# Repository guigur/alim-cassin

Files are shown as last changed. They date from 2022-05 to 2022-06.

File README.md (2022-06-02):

# alim-cassin
## Présentation
Ce PCB est un shield pour Arduino UNO.

Son but principal est de fournir à partir d'une batterie externe un rail **7V** très propre au régulateur linéaire de l'Arduino tout en générant également une alimentation **5V** pour alimenter un servomoteur. L'alimentation externe peut être coupée du système grâce au connecteur JST-XH3 où un bouton d'arrêt d'urgent NC se doit être connecté.

En découplant les alimentations, cela évite les resets intempestifs de l'Arduino lors d'efforts du servomoteur.

La version 2 du montage dispose d'un connecteur JST-XH4 compatible Groove afin d'y connecter un périphérique externe (dans notre cas un module bluetooth).
Un pont diviseur de tension est connecté sur le pin A0 permet également de mesurer la tension d'entrée jusqu'à 14V.

Enfin des LEDs permettent de visualiser l'état des rails d'alimentation.

## Schéma électrique
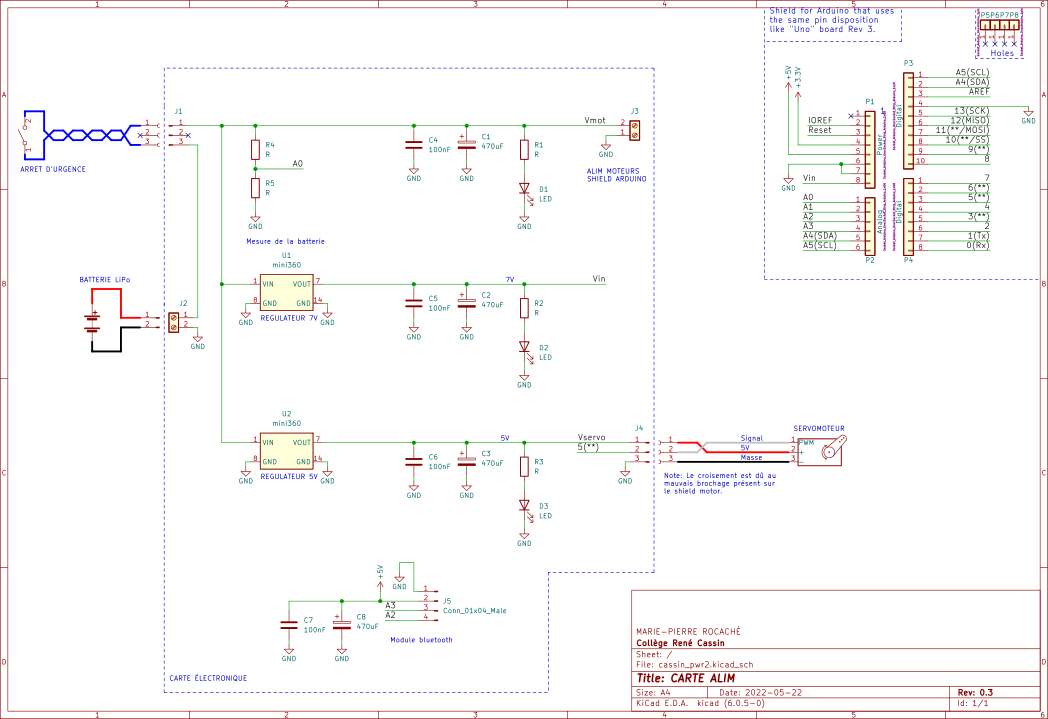
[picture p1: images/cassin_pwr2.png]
schematic Schéma électrique du PCB


## Rendu 3D
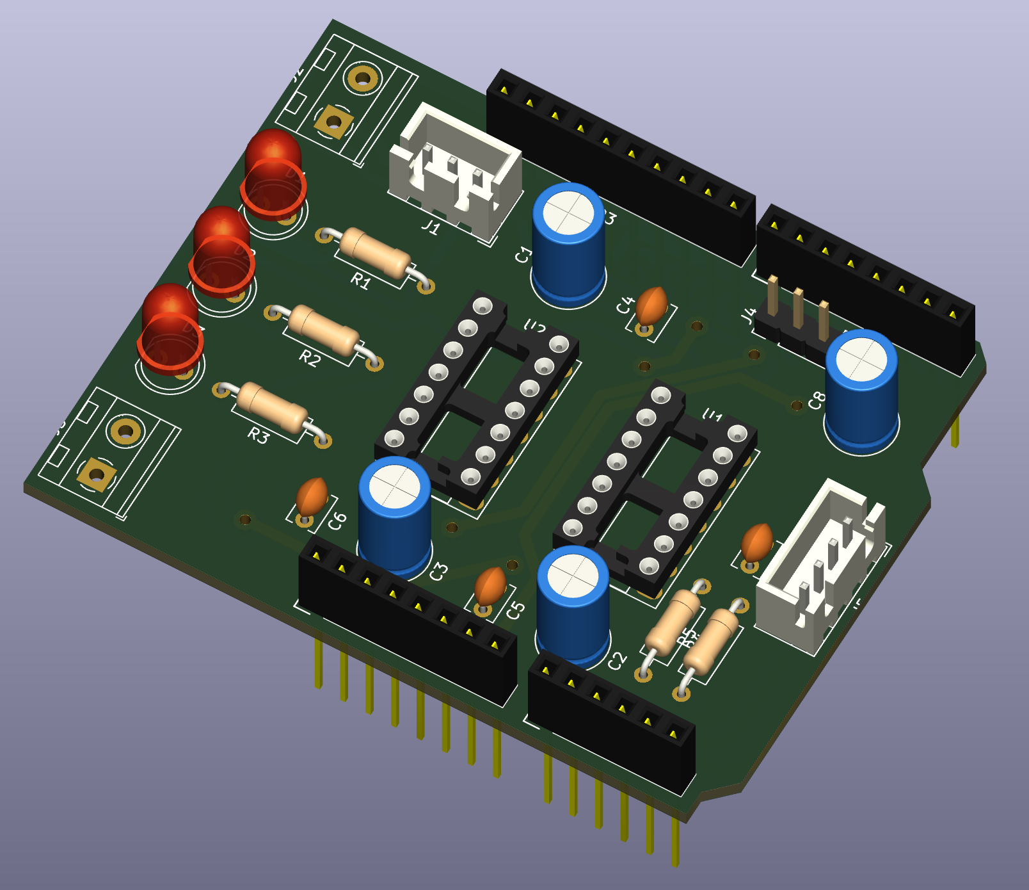
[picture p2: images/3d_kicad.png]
3D render of PCB Rendu 3D du PCB


## Le PCB (Prototype)
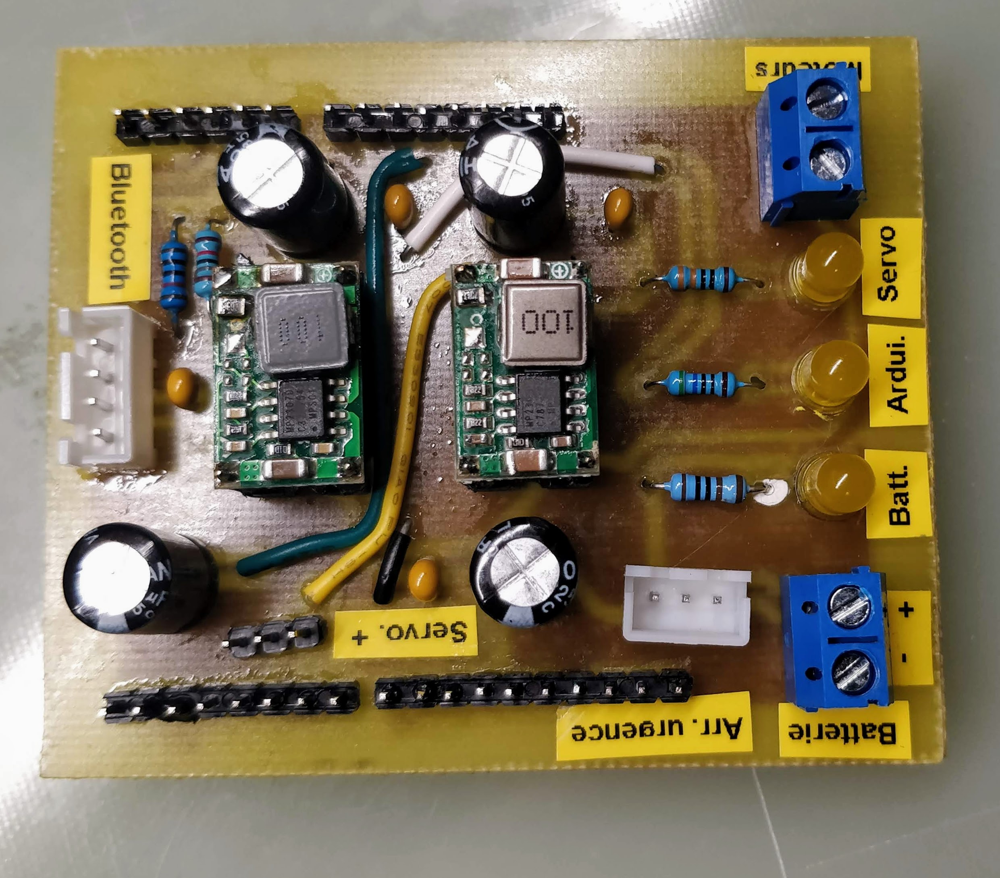
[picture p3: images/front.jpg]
Front of PCB Face du dessus du PCB

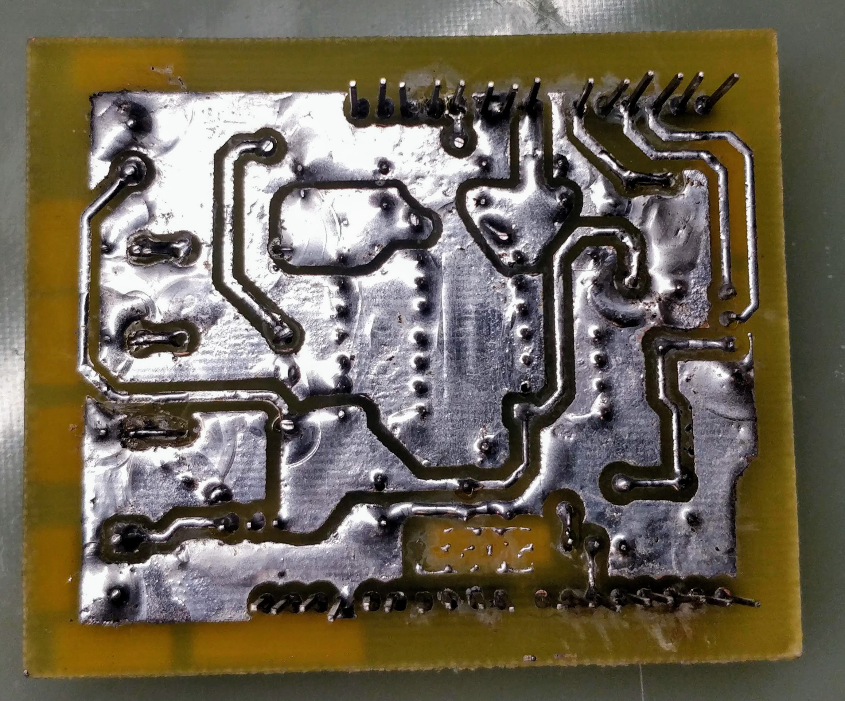
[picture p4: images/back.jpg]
Back of PCB Face du dessous du PCB


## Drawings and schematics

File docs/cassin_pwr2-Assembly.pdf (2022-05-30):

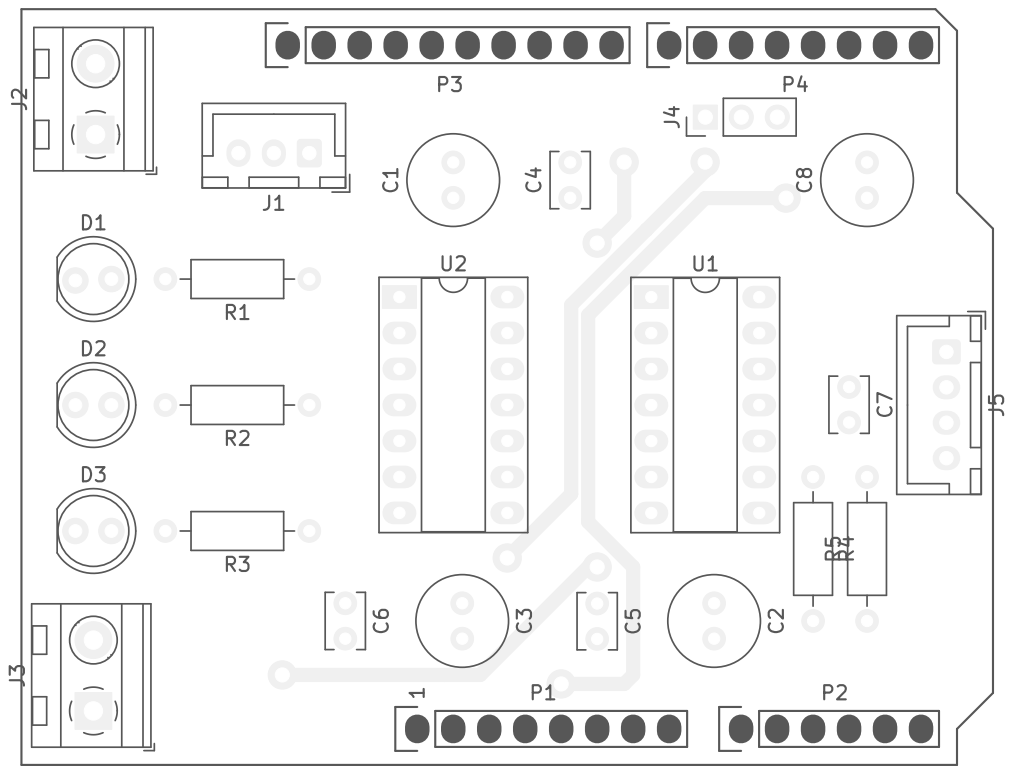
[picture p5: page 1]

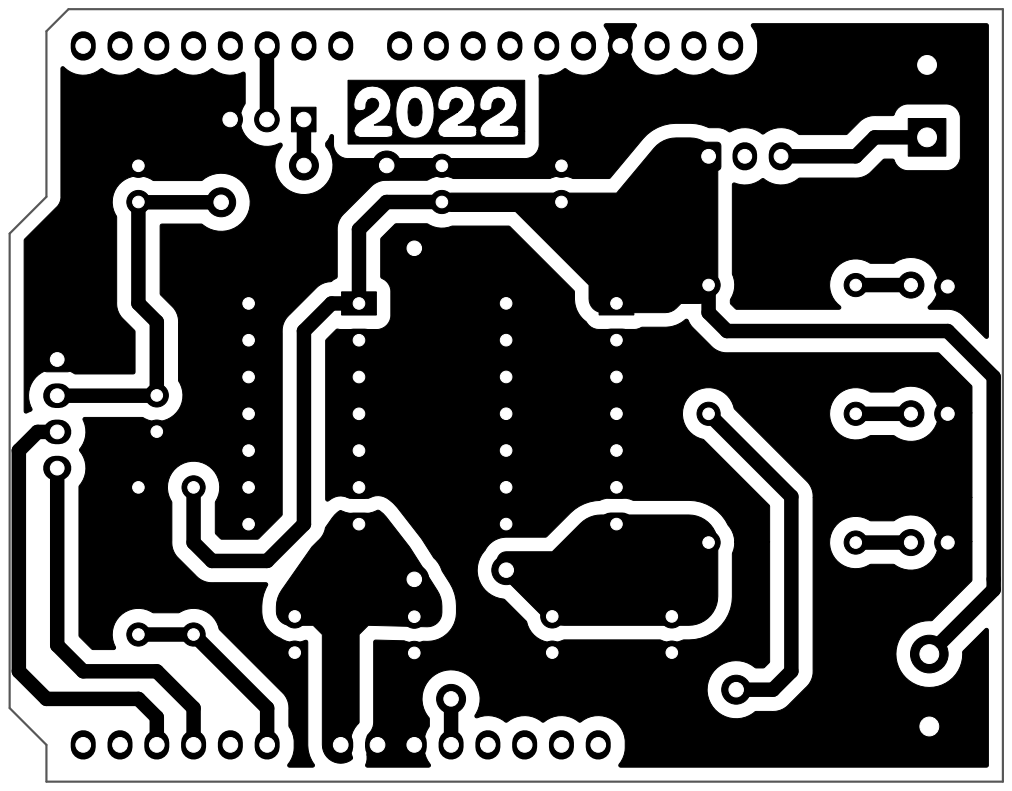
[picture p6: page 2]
D Date: lun. 30 mars 2015 KiCad E.D.A. kicad (6.0.5-0) Size: A4; Rev:; Id: 1/1 Title:; File: cassin_pwr2.kicad_pcb; Sheet: Assembly

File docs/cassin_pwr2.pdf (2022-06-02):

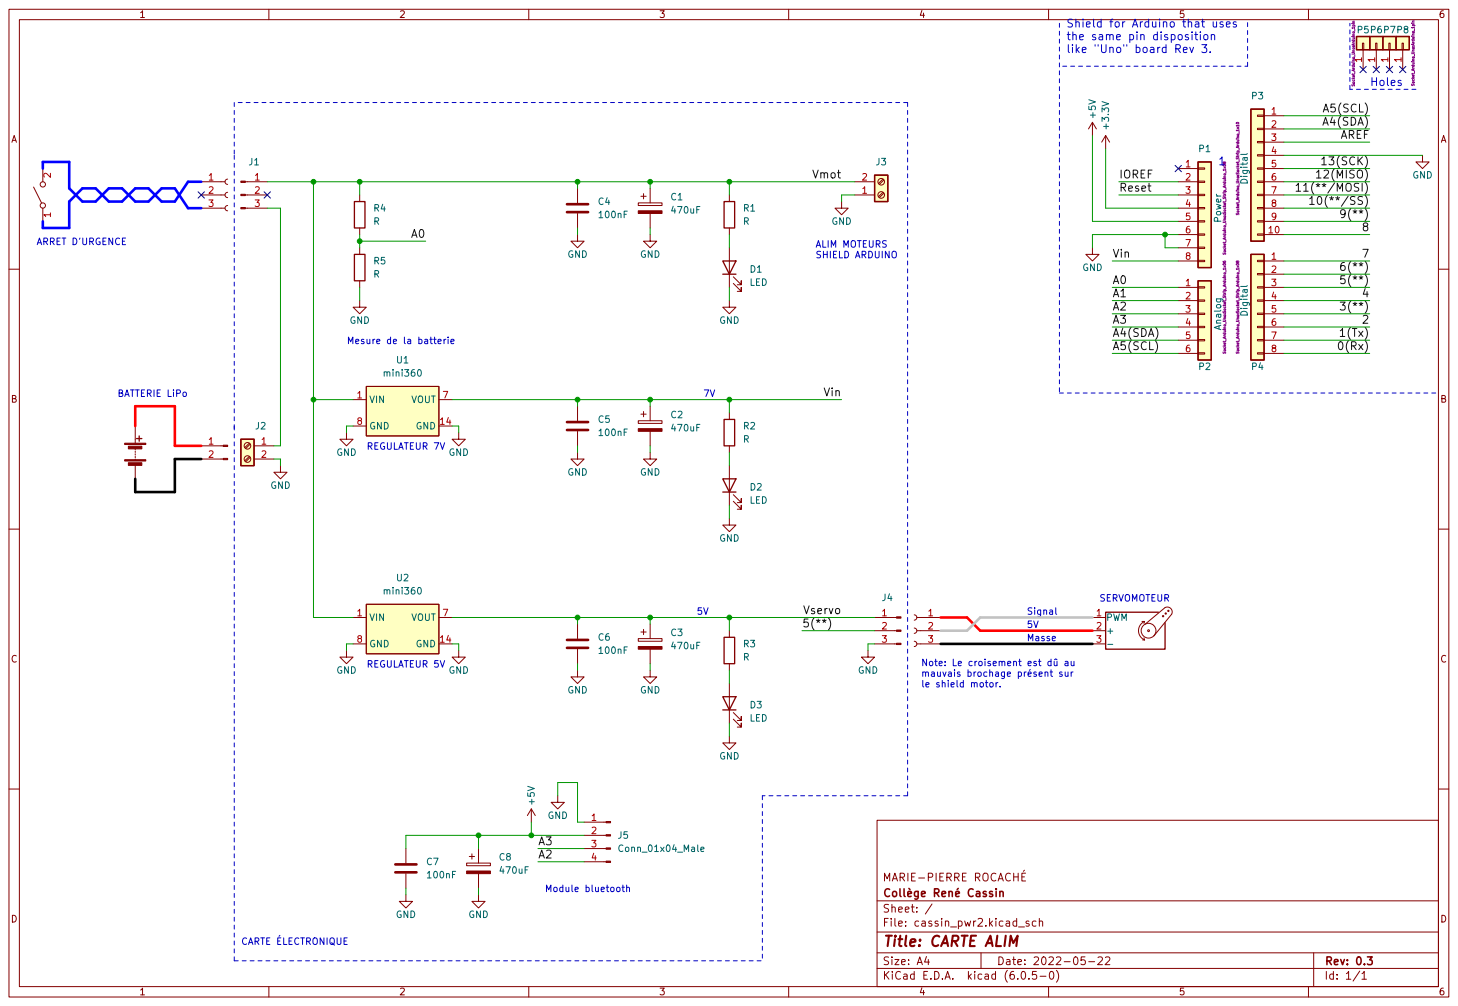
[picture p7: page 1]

1 Shield for Arduino that uses
the same pin disposition
like "Uno" board Rev 3.
J3 GND

Id: 1/1 Title: CARTE ALIM

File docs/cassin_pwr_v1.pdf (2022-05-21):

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

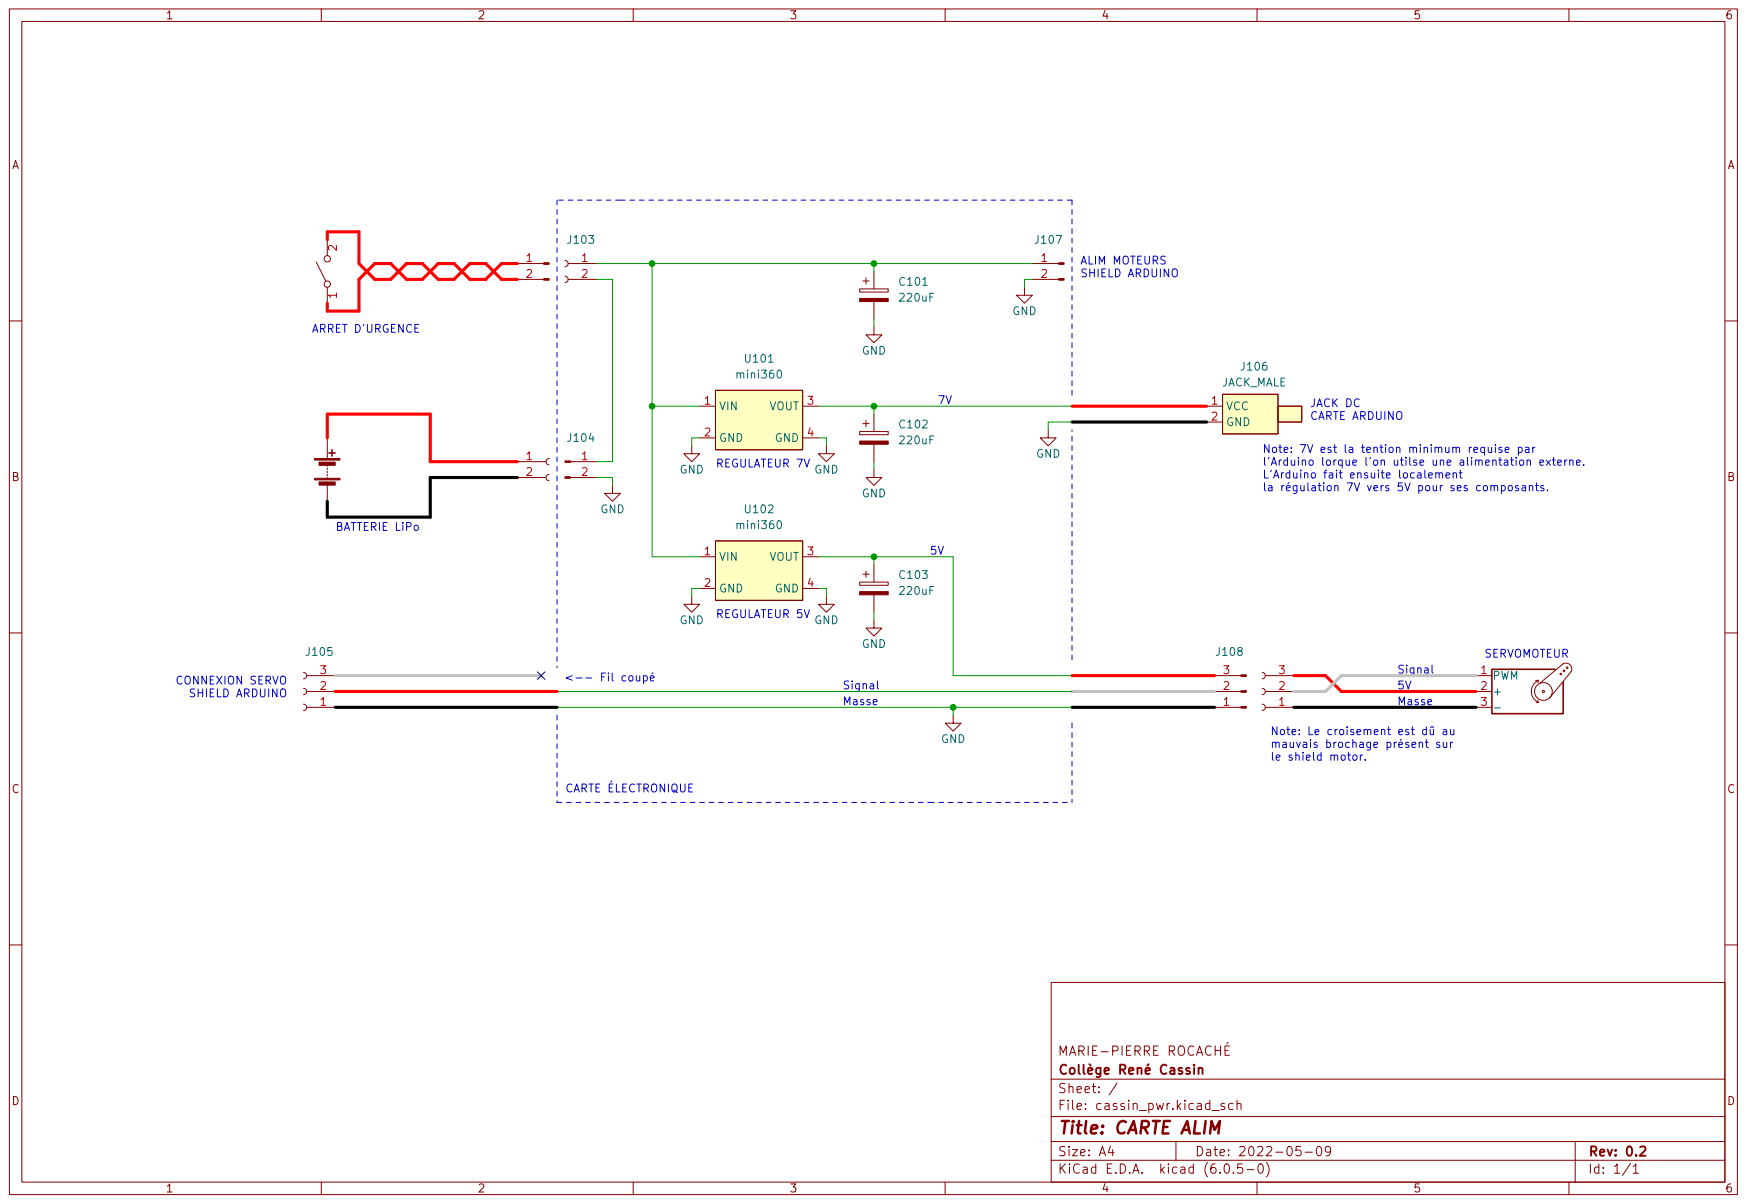
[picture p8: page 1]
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

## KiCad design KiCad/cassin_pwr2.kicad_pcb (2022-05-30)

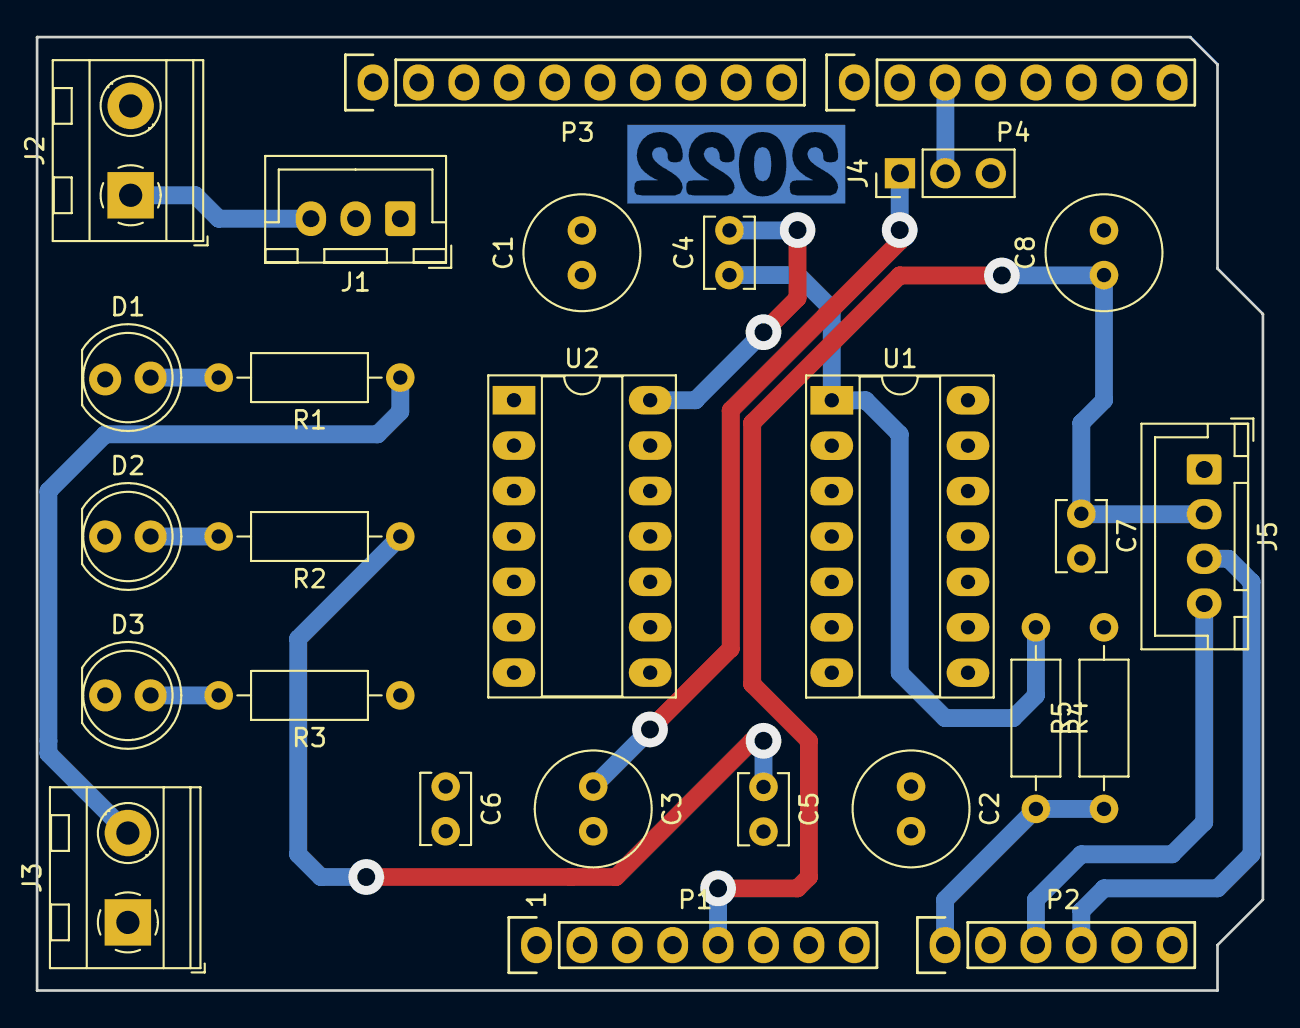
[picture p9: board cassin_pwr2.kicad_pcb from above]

Board: 2 copper layers, 68.6 x 53.3 mm, 28 parts (1 on the bottom side), 15 nets.

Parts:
C1, C2, C3, C8: 470uF; C_Radial_D6.3mm_H11.0mm_P2.50mm
C4, C5, C6, C7: 100nF; C_Disc_D3.8mm_W2.6mm_P2.50mm
D1, D2, D3: LED; LED_D5.0mm
J1: Conn_01x03_Male; JST_XH_B3B-XH-A_1x03_P2.50mm_Vertical
J2, J3: Screw_Terminal_01x02; TerminalBlock_MetzConnect_Type094_RT03502HBLU_1x02_P5.00mm_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
J4: Conn_01x03_Male; PinHeader_1x03_P2.54mm_Vertical
J5: Conn_01x04_Male; JST_XH_B4B-XH-A_1x04_P2.50mm_Vertical
P1: Power; Socket_Strip_Arduino_1x08
P2: Analog; Socket_Strip_Arduino_1x06
P3: Digital; Socket_Strip_Arduino_1x10
P4: Digital; Socket_Strip_Arduino_1x08
R1, R2, R3, R4, R5: R; R_Axial_DIN0207_L6.3mm_D2.5mm_P10.16mm_Horizontal
U1, U2: mini360; DIP-14_W7.62mm_Socket_LongPads
kibuzzard-628A722A: G***; kibuzzard-628A722A

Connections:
+5V: C7.1, C8.1, J5.2, P1.5
/5(**): J4.2, P4.3
/A0: P2.1, R4.2, R5.1
/A2: J5.4, P2.3
/A3: J5.3, P2.4
/A4(SDA): P2.5, P3.2
/A5(SCL): P2.6, P3.1
/Vin: C2.1, C5.1, P1.8, R2.1, U1.7 (VOUT)
/Vmot: C1.1, C4.1, J1.1, J3.2, R1.1, R4.1, U1.1 (VIN), U2.1 (VIN)
/Vservo: C3.1, C6.1, J4.1, R3.1, U2.7 (VOUT)
GND: C1.2, C2.2, C3.2, C4.2, C5.2, C6.2, C7.2, C8.2, D1.1 (K), D2.1 (K), D3.1 (K), J2.2, J3.1, J4.3, J5.1, P1.6, P1.7, P3.4, R5.2, U1.2 (GND), U1.3 (GND), U1.4 (GND), U1.5 (GND), U1.6 (GND), U1.8 (GND), U1.9 (GND), U1.10 (GND), U1.11 (GND), U1.12 (GND), U1.13 (GND), U1.14 (GND), U2.2 (GND), U2.3 (GND), U2.4 (GND), U2.5 (GND), U2.6 (GND), U2.8 (GND), U2.9 (GND), U2.10 (GND), U2.11 (GND), U2.12 (GND), U2.13 (GND), U2.14 (GND)
unnamed: D1.2 (A), R1.2
unnamed: D2.2 (A), R2.2
unnamed: D3.2 (A), R3.2
unnamed: J1.3, J2.1
